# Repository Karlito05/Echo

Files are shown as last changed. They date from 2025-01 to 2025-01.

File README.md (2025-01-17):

# Echo
The best-sounding ortholinear keyboard.

## General Information
This project utilizes three main programs: [Ergogen](https://github.com/ergogen/ergogen), [Autodesk Fusion 360](https://www.autodesk.com/products/fusion-360/overview), and [KiCad](https://www.kicad.org/).

- The `config.yaml` file contains the Ergogen script used to generate the output files.
- 3D model files, including the case, switch plate, and keycaps, are located in the `./3D models` directory. Custom keycaps were modeled due to non-standard sizes.
- The entire keyboard is approximately 7 mm thick (excluding keycaps and switches).

### Why custom keycaps?
The keycaps sizes are not standard. For example in normal sets there is no R3 and R4 3U keycap. So I had to make my own.
## A Quick Overview of Ergogen
Ergogen is a generator utility for ergonomic keyboard layouts, including plates, cases, and PCBs. [Learn more about Ergogen here](https://docs.ergogen.xyz/)

In Ergogen, six main elements are used:
- **Meta**: Metadata
- **Units**: Defines unit-specific configurations
- **Zones**: Configurations for rows and columns
- **Outlines**: Outlines of the keyboard
- **PCBs**: Printed circuit board generation
- **Cases**: Case designs

Each of these elements is subdivided into more specific categories.

## How to Build from the Ergogen File
Follow these steps to build from the Ergogen file:

1. Ensure Ergogen and the `footprints` folder are in the same directory as `config.yaml`.
2. Open your terminal.
3. Navigate to the current working directory using `cd`.
4. Run the command:  
   ```bash
   ergogen .
   ```
This will generate an `output` folder containing the output files.

## Final Build
The keyboard has not been built yet. The plan includes:
- Switches: Lubed Akko Rosewood switches (hot-swap configuration)
- Lubed stabilizers
- Additional Sound-improving modifications

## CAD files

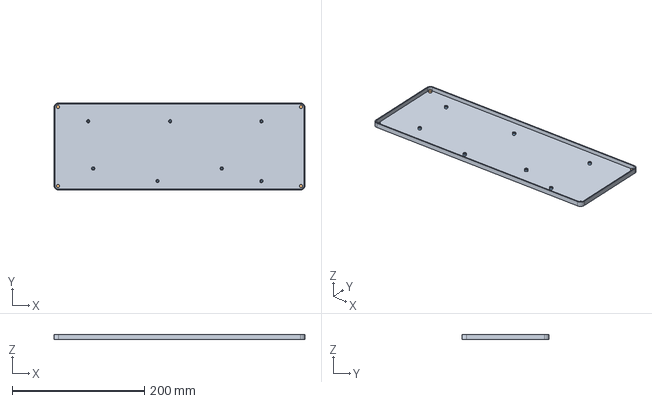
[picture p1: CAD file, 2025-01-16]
3d models/Bottom Plate.step
379.4 x 131.8 x 7.10 mm

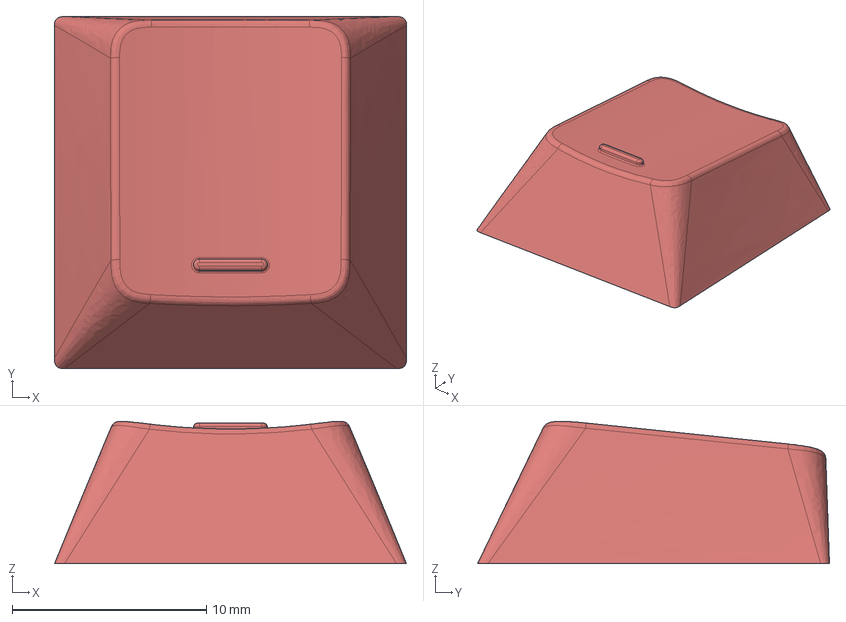
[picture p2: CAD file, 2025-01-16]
3d models/keycaps/R3_1u_Barred_2x.step
18.1 x 18.1 x 7.32 mm

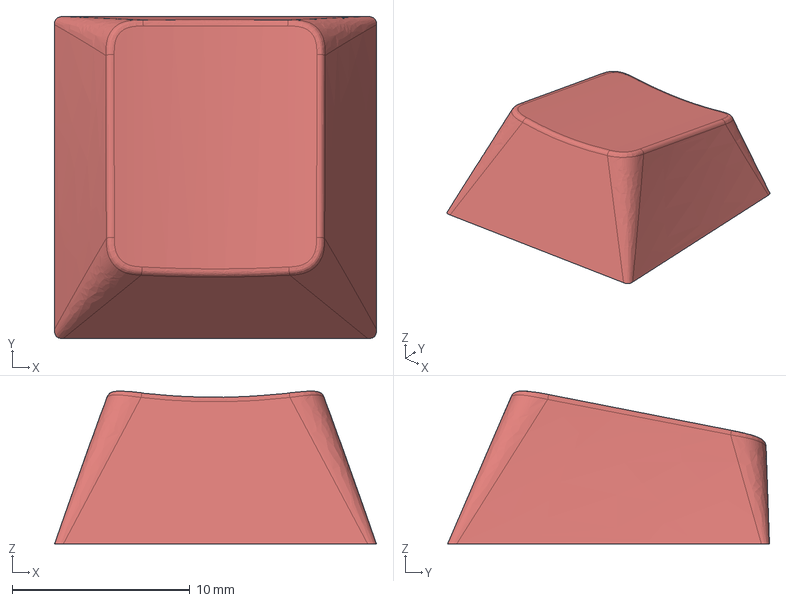
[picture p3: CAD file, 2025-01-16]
3d models/keycaps/R4_1u_13x.step
18.1 x 18.1 x 8.60 mm

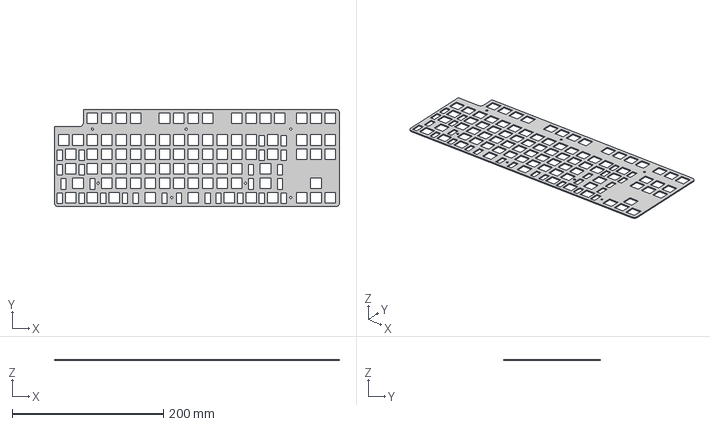
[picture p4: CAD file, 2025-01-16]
3d models/Switchplate.step
376.4 x 128.8 x 1.50 mm

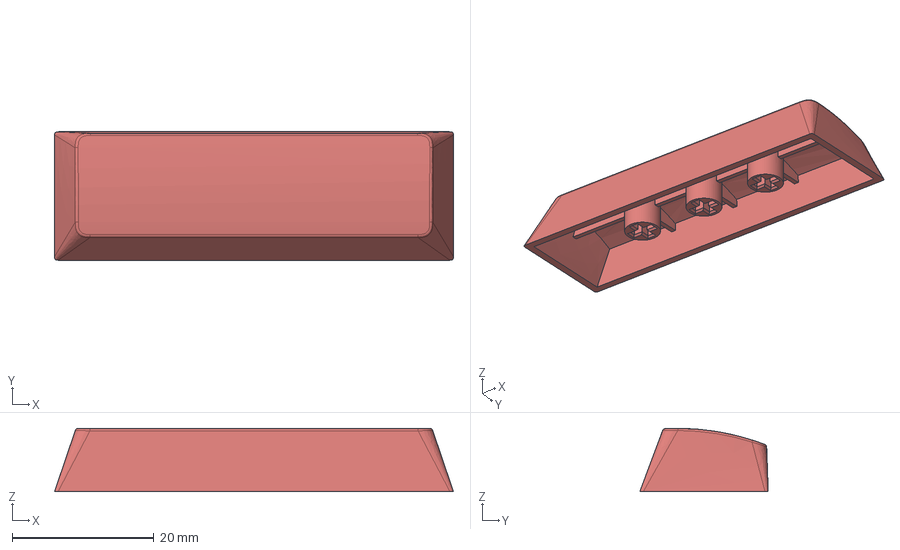
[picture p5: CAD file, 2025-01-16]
3d models/keycaps/Convex_3u_2x.step
56.2 x 18.1 x 8.92 mm

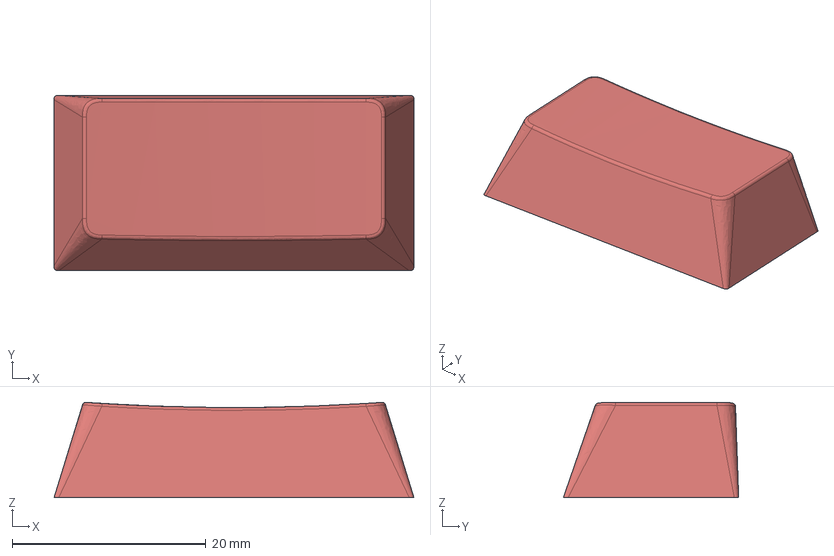
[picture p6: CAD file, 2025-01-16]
3d models/keycaps/R1_2u_1x.step
37.1 x 18.1 x 9.83 mm

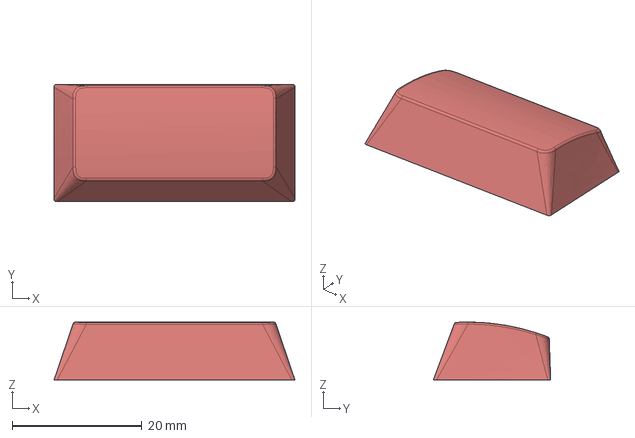
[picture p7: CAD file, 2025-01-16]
3d models/keycaps/Convex_2u_4x.step
37.1 x 18.1 x 8.92 mm

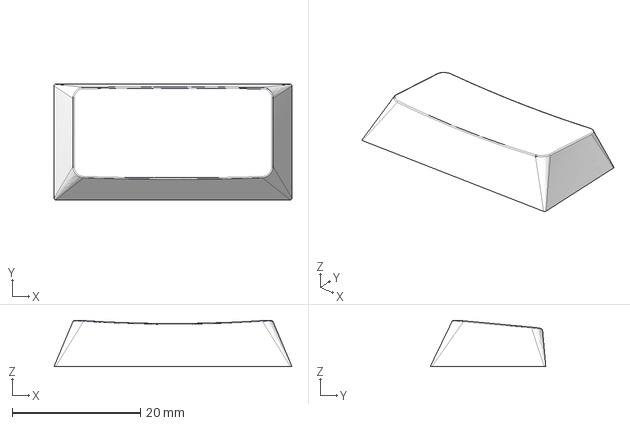
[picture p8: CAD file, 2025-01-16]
3d models/keycaps/R3_2u_1x.step
37.1 x 18.0 x 7.20 mm

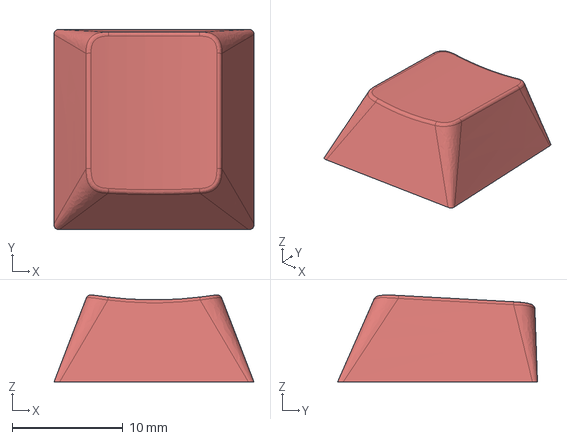
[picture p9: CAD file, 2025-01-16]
3d models/keycaps/R2_1u_15x.step
18.1 x 18.1 x 7.87 mm

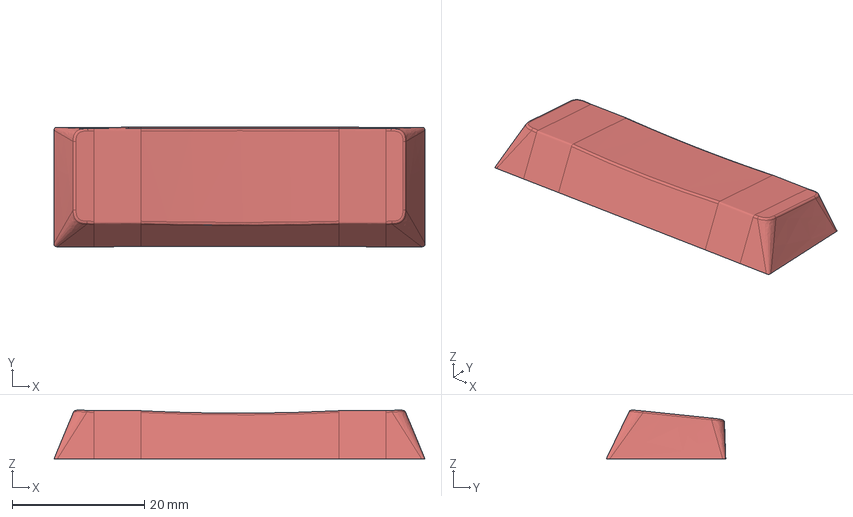
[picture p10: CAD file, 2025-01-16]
3d models/keycaps/R3_3u_1x.step
56.2 x 18.1 x 7.39 mm

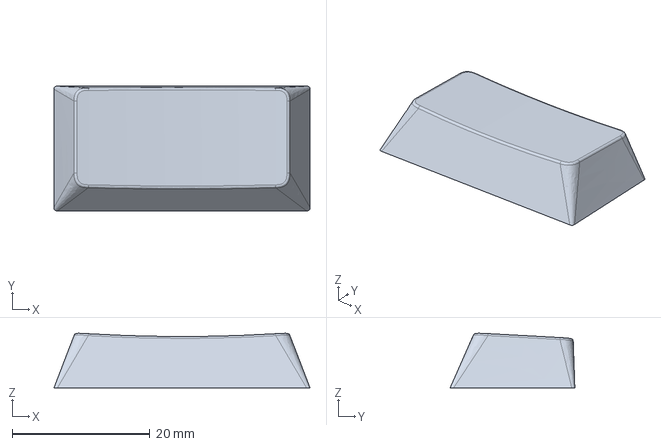
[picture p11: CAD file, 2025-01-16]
3d models/keycaps/R2_2u_2x.step
37.1 x 18.1 x 7.91 mm

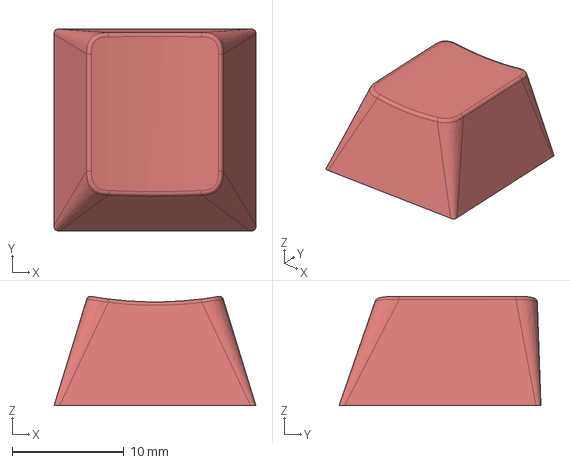
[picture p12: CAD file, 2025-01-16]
3d models/keycaps/R1_1u_33x.step
18.1 x 18.1 x 9.80 mm

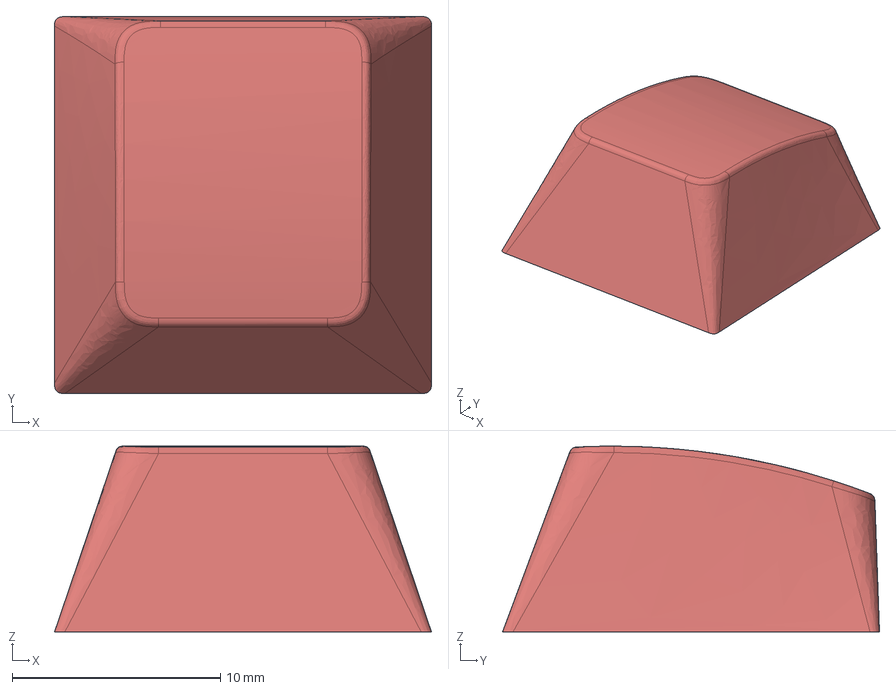
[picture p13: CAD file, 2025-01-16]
3d models/keycaps/Convex_1u_2x.step
18.1 x 18.1 x 8.92 mm

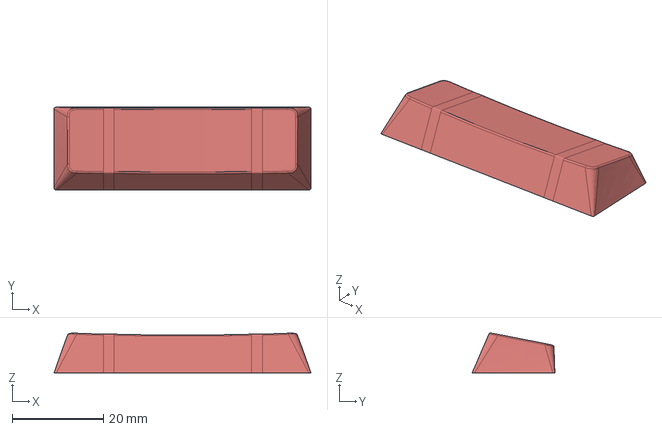
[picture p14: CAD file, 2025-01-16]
3d models/keycaps/R4_3u_2x.step
56.2 x 18.1 x 8.70 mm

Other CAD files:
3d models/keycaps/R3_1u_2x.step
3d models/keycaps/R3_1u_10x.step

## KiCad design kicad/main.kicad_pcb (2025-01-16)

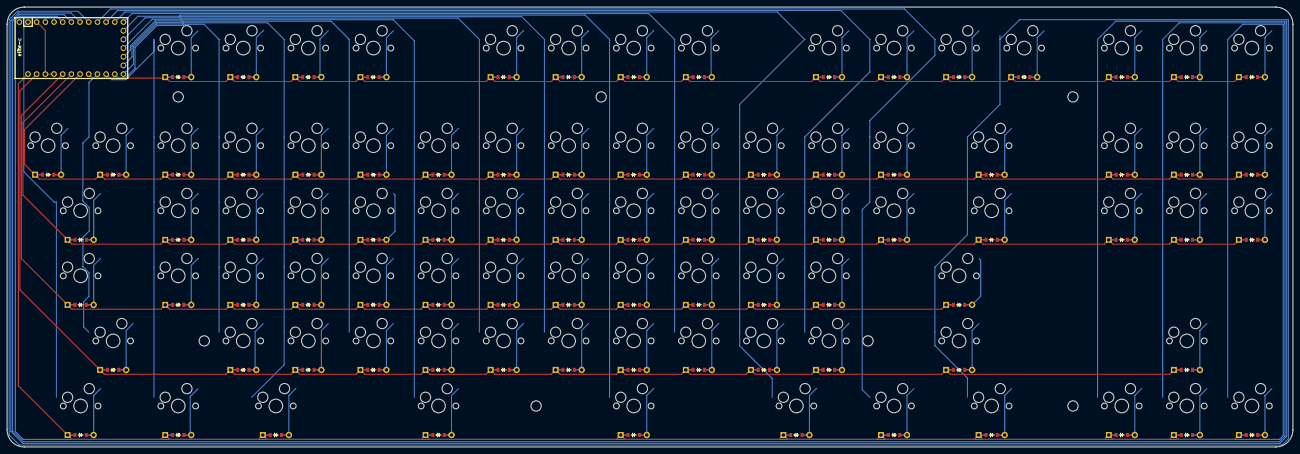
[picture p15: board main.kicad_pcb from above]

Board: 2 copper layers, 376.4 x 128.8 mm, 174 parts (0 on the bottom side), 111 nets.

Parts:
D1, D2, D3, D4, D5, D6, D7, D8, D9, D10, D11, D12, D13, D14, D15, D16, D17, D18, D19, D20, D21, D22, D23, D24, D25, D26, D27, D28, D29, D30, D31, D32, D33, D34, D35, D36, D37, D38, D39, D40, D41, D42, D43, D44, D45, D46, D47, D48, D49, D50, D51, D52, D53, D54, D55, D56, D57, D58, D59, D60, D61, D62, D63, D64, D65, D66, D67, D68, D69, D70, D71, D72, D73, D74, D75, D76, D77, D78, D79, D80, D81, D82, D83, D84, D85, D86, D87: ComboDiode
S1, S2, S3, S4, S5, S6, S7, S8, S9, S10, S11, S12, S13, S14, S15, S16, S17, S18, S19, S20, S21, S22, S23, S24, S25, S26, S27, S28, S29, S30, S31, S32, S33, S34, S35, S36, S37, S38, S39, S40, S41, S42, S43, S44, S45, S46, S47, S48, S49, S50, S51, S52, S53, S54, S55, S56, S57, S58, S59, S60, S61, S62, S63, S64, S65, S66, S67, S68, S69, S70, S71, S72, S73, S74, S75, S76, S77, S78, S79, S80, S81, S82, S83, S84, S85, S86, S87: MX

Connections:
B0: S47.1, S48.1, S49.1, S55.1
B1: S44.1, S45.1, S61.1, S73.1
B2: S36.1, S37.1, S38.1, S39.1, S60.1, S71.1
B3: S40.1, S41.1, S42.1, S43.1, S72.1
B4: S4.1, S5.1, S6.1, S7.1, S64.1
B5: S8.1, S9.1, S10.1, S11.1, S57.1, S65.1
B6: S32.1, S33.1, S34.1, S35.1, S70.1
B7: S12.1, S13.1, S14.1, S15.1, S66.1
C6: D63.1, D64.1, D65.1, D66.1, D67.1, D68.1, D69.1, D70.1, D71.1, D72.1, D73.1, D74.1, D75.1, D76.1, D77.1
C7: S20.1, S21.1, S22.1, S23.1, S67.1
D0: D2.1, D6.1, D10.1, D14.1, D18.1, D22.1, D26.1, D30.1, D34.1, D38.1, D42.1, D44.1, D48.1, D53.1, D79.1, D83.1, D86.1
D1: D1.1, D5.1, D9.1, D13.1, D17.1, D21.1, D25.1, D29.1, D33.1, D37.1, D41.1, D47.1, D52.1
D2: D4.1, D8.1, D12.1, D16.1, D20.1, D24.1, D28.1, D32.1, D36.1, D40.1, D46.1, D51.1, D82.1
D3: D55.1, D56.1, D57.1, D58.1, D59.1, D60.1, D61.1, D62.1, D78.1, D81.1, D85.1
D4: D3.1, D7.1, D11.1, D15.1, D19.1, D23.1, D27.1, D31.1, D35.1, D39.1, D43.1, D45.1, D49.1, D50.1, D54.1, D80.1, D84.1, D87.1
D5: S16.1, S17.1, S18.1, S19.1, S58.1
D7: S46.1, S50.1
E6: S1.1, S2.1, S3.1, S56.1, S63.1
F0: S28.1, S29.1, S30.1, S31.1, S59.1, S69.1
F1: S24.1, S25.1, S26.1, S27.1, S68.1
F4: S77.1, S85.1, S86.1, S87.1
F5: S76.1, S81.1, S82.1, S83.1, S84.1
F6: S75.1, S78.1, S79.1, S80.1
F7: S51.1, S52.1, S53.1, S54.1, S62.1, S74.1
eight_eight: D31.2, S31.2
eight_i: D30.2, S30.2
eight_k: D29.2, S29.2
eight_m: D28.2, S28.2
eighth_f7: D69.2, S69.2
eleventh_dash: D43.2, S43.2
eleventh_f10: D72.2, S72.2
eleventh_openCurlyBrace: D42.2, S42.2
eleventh_questionMark: D40.2, S40.2
eleventh_quotes: D41.2, S41.2
fifteenth_scrLk: D76.2, S76.2
fifth_f4: D66.2, S66.2
fifth_five: D19.2, S19.2
fifth_g: D17.2, S17.2
fifth_spaceR: D59.2, S59.2
fifth_t: D18.2, S18.2
fifth_v: D16.2, S16.2
first_a: D1.2, S1.2
first_backspace: D54.2, S54.2
first_capsLock: D47.2, S47.2
first_ctrlL: D55.2, S55.2
first_delete: D79.2, S79.2
first_enter: D52.2, S52.2
first_esc: D49.2, S49.2
first_insert: D80.2, S80.2
first_lShift: D46.2, S46.2
first_left: D78.2, S78.2
first_one: D3.2, S3.2
first_pipe: D53.2, S53.2
first_q: D2.2, S2.2
first_rShift: D51.2, S51.2
first_tab: D48.2, S48.2
fourteenth_prntSc: D75.2, S75.2
fourth_c: D12.2, S12.2
fourth_f: D13.2, S13.2
fourth_f3: D65.2, S65.2
fourth_four: D15.2, S15.2
fourth_r: D14.2, S14.2
fourth_spaceL: D58.2, S58.2
ninth_comma: D32.2, S32.2
ninth_ctrlR: D62.2, S62.2
ninth_f8: D70.2, S70.2
ninth_l: D33.2, S33.2
ninth_nine: D35.2, S35.2
ninth_o: D34.2, S34.2
second_down: D81.2, S81.2
second_end: D83.2, S83.2
second_f1: D63.2, S63.2
second_home: D84.2, S84.2
second_s: D5.2, S5.2
second_tilde: D50.2, S50.2
second_two: D7.2, S7.2
second_up: D82.2, S82.2
second_w: D6.2, S6.2
second_windowsL: D56.2, S56.2
second_z: D4.2, S4.2
seventh_f6: D68.2, S68.2
seventh_j: D25.2, S25.2
seventh_n: D24.2, S24.2
seventh_seven: D27.2, S27.2
seventh_u: D26.2, S26.2
seventh_windowsR: D61.2, S61.2
sixteenth_pause: D77.2, S77.2
sixth_altGr: D60.2, S60.2
sixth_b: D20.2, S20.2
sixth_f5: D67.2, S67.2
sixth_h: D21.2, S21.2
sixth_six: D23.2, S23.2
sixth_y: D22.2, S22.2
tenth_dot: D36.2, S36.2
tenth_f9: D71.2, S71.2
tenth_p: D38.2, S38.2
tenth_semicolon: D37.2, S37.2
tenth_zero: D39.2, S39.2
third_alt: D57.2, S57.2
third_d: D9.2, S9.2
third_e: D10.2, S10.2
third_f2: D64.2, S64.2
third_pageDown: D86.2, S86.2
third_pageUp: D87.2, S87.2
third_right: D85.2, S85.2
third_three: D11.2, S11.2
third_x: D8.2, S8.2
thirteenth_f12: D74.2, S74.2
twelfth_closedCurlyBrace: D44.2, S44.2
twelfth_equals: D45.2, S45.2
twelfth_f11: D73.2, S73.2

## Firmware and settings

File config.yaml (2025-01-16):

meta:
  engine: 4.1.0
units:
  u: U # Ensure we are using 19.05!

  stabilizer_width: 7
  stabilizer_height: 14
  stabilizer_offset: -1 # This means south stabs, use `orient` to rotate them for north facing scenarios
  stabilizer_spacing_2u: u / 2 + stabilizer_width / 2 + ((23.8 / 2) - (14 / 2) - (stabilizer_width / 2)) # The complex formula has two magic numbers. 14 is the size of a switch cutout for a plate. 23.8 is the distance between each stabilizer on a 2-2.75u stabilizer, as specified by Cherry
  stabilizer_spacing_3u: u * ((3 - 1) / 2)

points:
  zones:
    alphanumeric:
      anchor:
        shift: [70, -185] # fix placement
      columns:
        first:
          rows:
            skipped:
              skip: true
            a:
              column_net: E6
              row_net: D1
            q:
              column_net: E6
              row_net: D0
            one:
              column_net: E6
              row_net: D4

        second:
          rows:
            z:
              column_net: B4
              row_net: D2
            s:
              column_net: B4
              row_net: D1
            w:
              column_net: B4
              row_net: D0
            two:
              column_net: B4
              row_net: D4

        third:
          rows:
            x:
              column_net: B5
              row_net: D2
            d:
              column_net: B5
              row_net: D1
            e:
              column_net: B5
              row_net: D0
            three:
              column_net: B5
              row_net: D4

        fourth:
          rows:
            c:
              column_net: B7
              row_net: D2
            f:
              column_net: B7
              row_net: D1
            r:
              column_net: B7
              row_net: D0
            four:
              column_net: B7
              row_net: D4

        fifth:
          rows:
            v:
              column_net: D5
              row_net: D2
            g:
              column_net: D5
              row_net: D1
            t:
              column_net: D5
              row_net: D0
            five:
              column_net: D5
              row_net: D4

        sixth:
          rows:
            b:
              column_net: C7
              row_net: D2
            h:
              column_net: C7
              row_net: D1
            y:
              column_net: C7
              row_net: D0
            six:
              column_net: C7
              row_net: D4

        seventh:
          rows:
            n:
              column_net: F1
              row_net: D2
            j:
              column_net: F1
              row_net: D1
            u:
              column_net: F1
              row_net: D0
            seven:
              column_net: F1
              row_net: D4

        eight:
          rows:
            m:
              column_net: F0
              row_net: D2
            k:
              column_net: F0
              row_net: D1
            i:
              column_net: F0
              row_net: D0
            eight:
              column_net: F0
              row_net: D4

        ninth:
          rows:
            comma:
              column_net: B6
              row_net: D2
            l:
              column_net: B6
              row_net: D1
            o:
              column_net: B6
              row_net: D0
            nine:
              column_net: B6
              row_net: D4

        tenth:
          rows:
            dot:
              column_net: B2
              row_net: D2
            semicolon:
              column_net: B2
              row_net: D1
            p:
              column_net: B2
              row_net: D0
            zero:
              column_net: B2
              row_net: D4

        eleventh:
          rows:
            questionMark:
              column_net: B3
              row_net: D2
            quotes:
              column_net: B3
              row_net: D1
            openCurlyBrace:
              column_net: B3
              row_net: D0
            dash:
              column_net: B3
              row_net: D4

        twelfth:
          rows:
            skipped1:
              skip: true
            skipped2:
              skip: true
            closedCurlyBrace:
              column_net: B1
              row_net: D0
            equals:
              column_net: B1
              row_net: D4

    modifierKeysL1:
      anchor:
        ref: alphanumeric_first_skipped
        shift: [-1U, 0]
      columns:
        first:
          rows:
            lShift:
              width: 2.95u
              bind: [1u, 0]
              column_net: D7
              row_net: D2
              tags: 3u_stabilizers
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
